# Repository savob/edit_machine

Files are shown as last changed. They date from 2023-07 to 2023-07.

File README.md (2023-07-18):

# Edit Machine

A hardware based goal tracker I made for a friend. The goal was simple: have buttons that illuminate LEDs to mark off completed tasks, another LED to flash when all goals are marked off, and to top it all off - a reset switch.

One requirement that was imposed on the project was that **we were to exclusively use material I already had laying about my apartment**, ideally reusing parts harvested off of other circuit boards I kept around for this purpose. 

Mechanically, there was a desire to have a space between the buttons and LEDs to record the goals corresponding to each row.

# Outcome

The final circuit was soldered on a perf(erated) board, which after *much* debugging made me long for a custom circuit board! It would probably surprize no one that this did not work on the first try. I'm relieved and a wee bit stupified that we didn't actually fry any chips in the process.

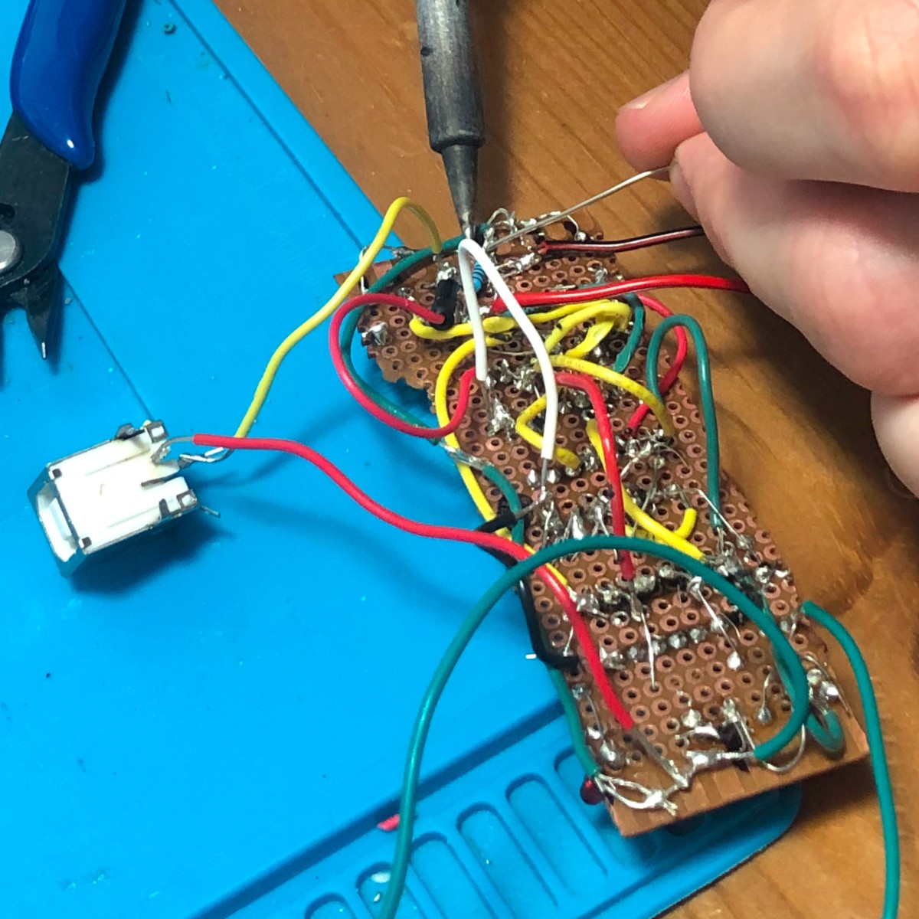
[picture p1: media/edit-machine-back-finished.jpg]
Rear view


By placing the chips in the middle I naturally created a space for the goals to be recorded inbetween the LEDs and the buttons. The chip cases can even act as fairly even supports for the writing pad above. *Note: that capacitor in the middle was bent down after the picture was taken.*

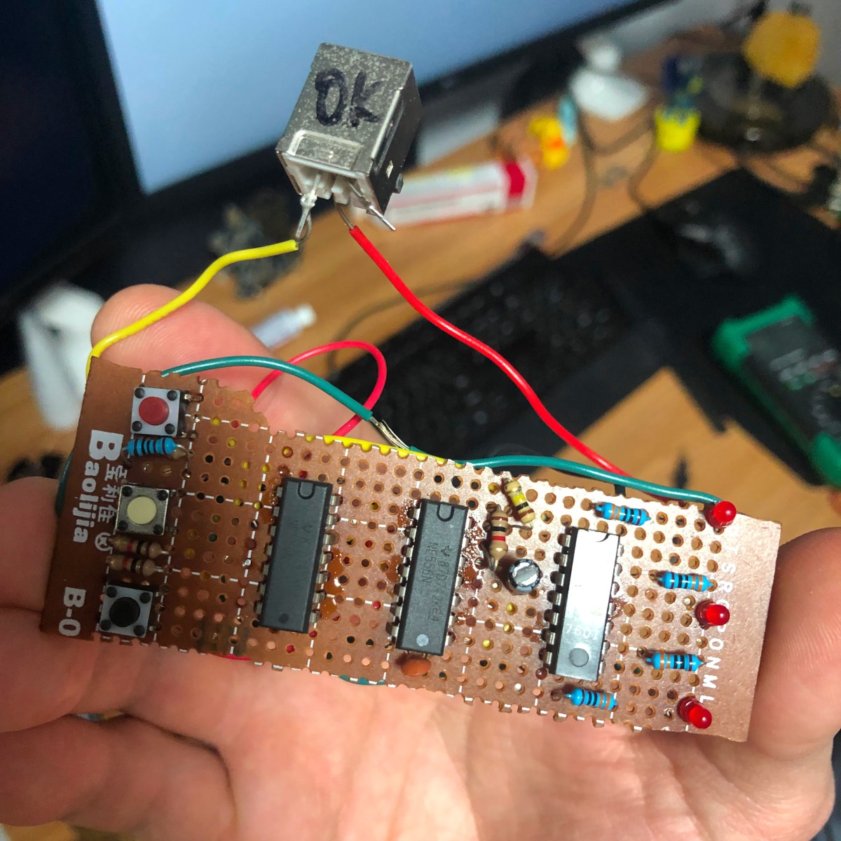
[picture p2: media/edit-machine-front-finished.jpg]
Front view


# The Circuitry

Originally I was planning to use some basic OR logic chips feeding into themselves to act as the toggles for the LEDs, however the chips I had were incorrectly labelled and were in fact XORs. So I ended up using some 556 timer chips as RS flip-flops for this instead. The driving for the final LED when all the goals are complete was accomplished using a chain of ANDs to combine the outputs for all the LEDs to enable the remaining timer in the 556's.

Schematic

I have made a preliminary custom circuit board which is a rough proxy of what the prototype was and is included as part of this project. Although it will function, it's dimesions and arrangement may change before I commit to having it made.

## Software Used

The circuit files were initially prepared in KiCad 7.0.5.

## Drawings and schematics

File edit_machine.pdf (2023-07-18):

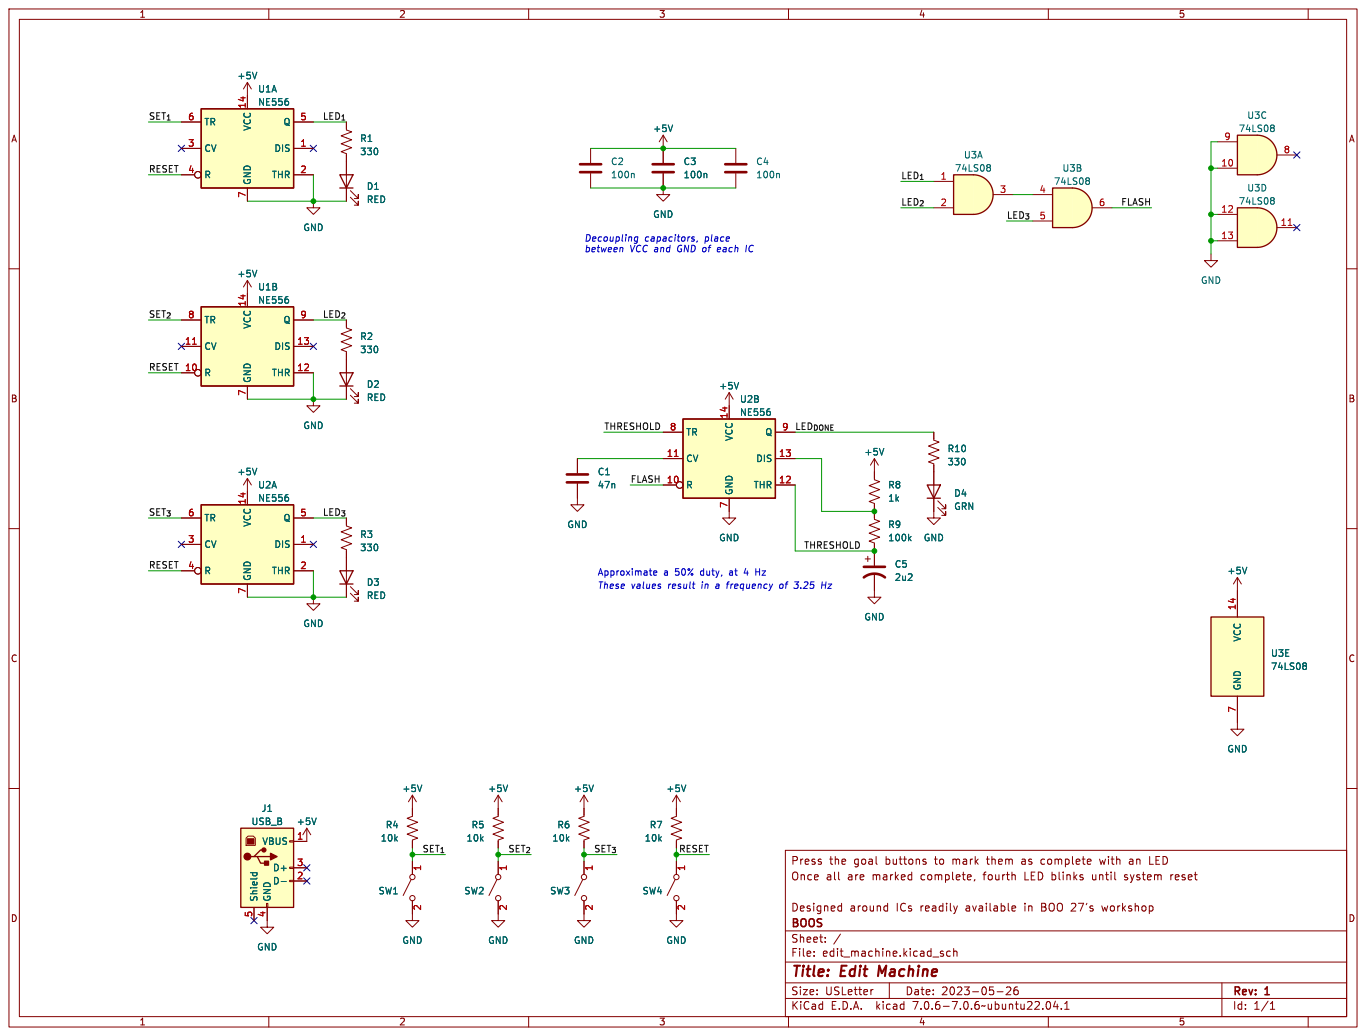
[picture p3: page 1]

between VCC and GND of each IC

Id: 1/1 Title: Edit Machine

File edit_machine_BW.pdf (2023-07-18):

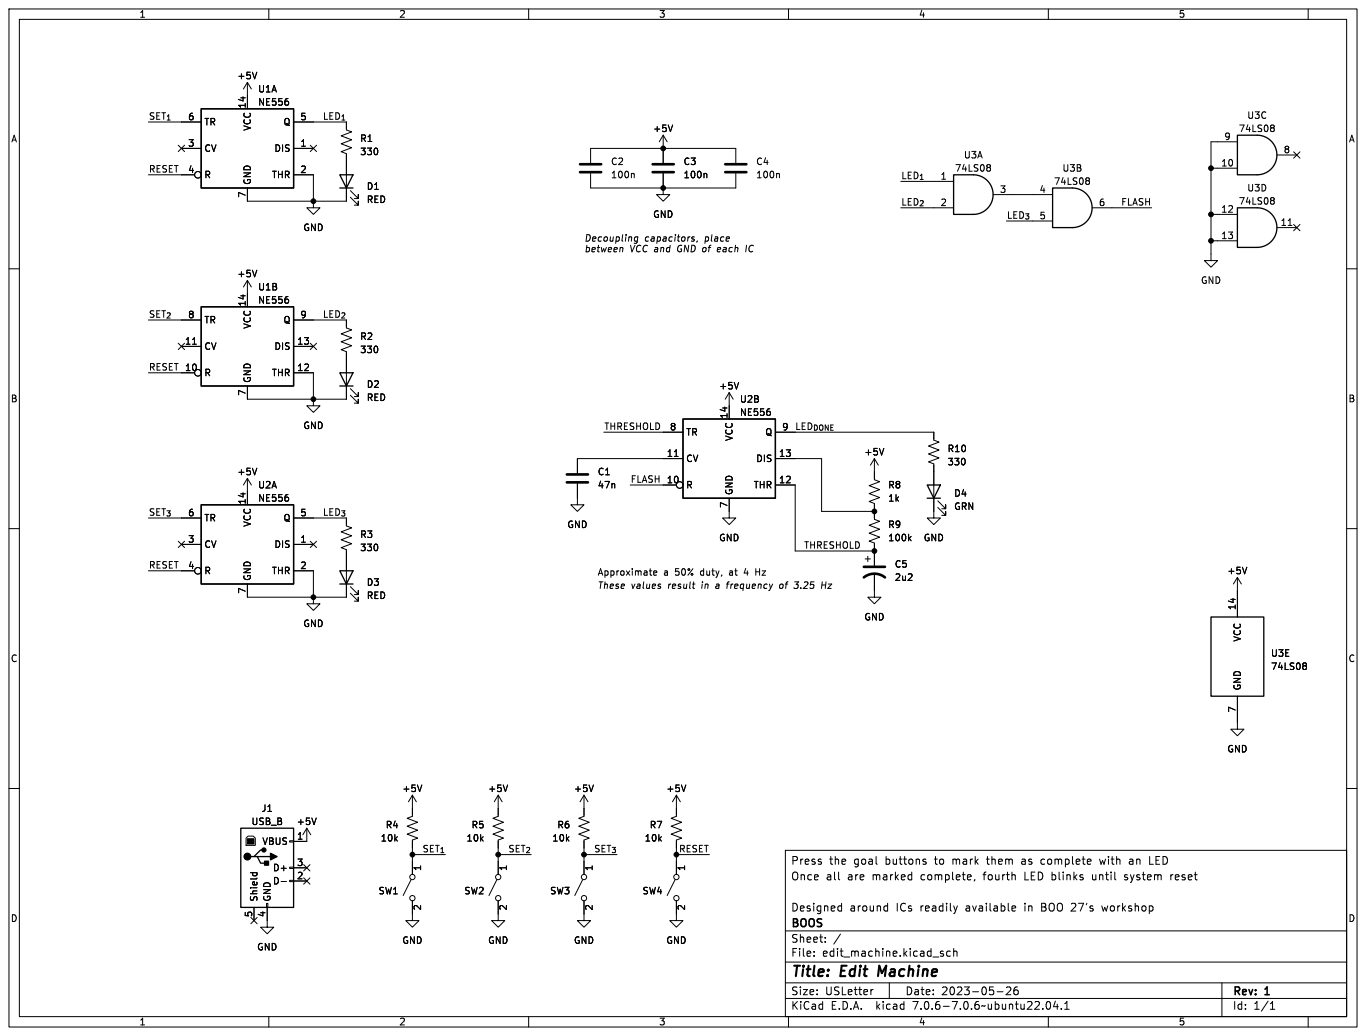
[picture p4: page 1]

between VCC and GND of each IC

Id: 1/1 Title: Edit Machine

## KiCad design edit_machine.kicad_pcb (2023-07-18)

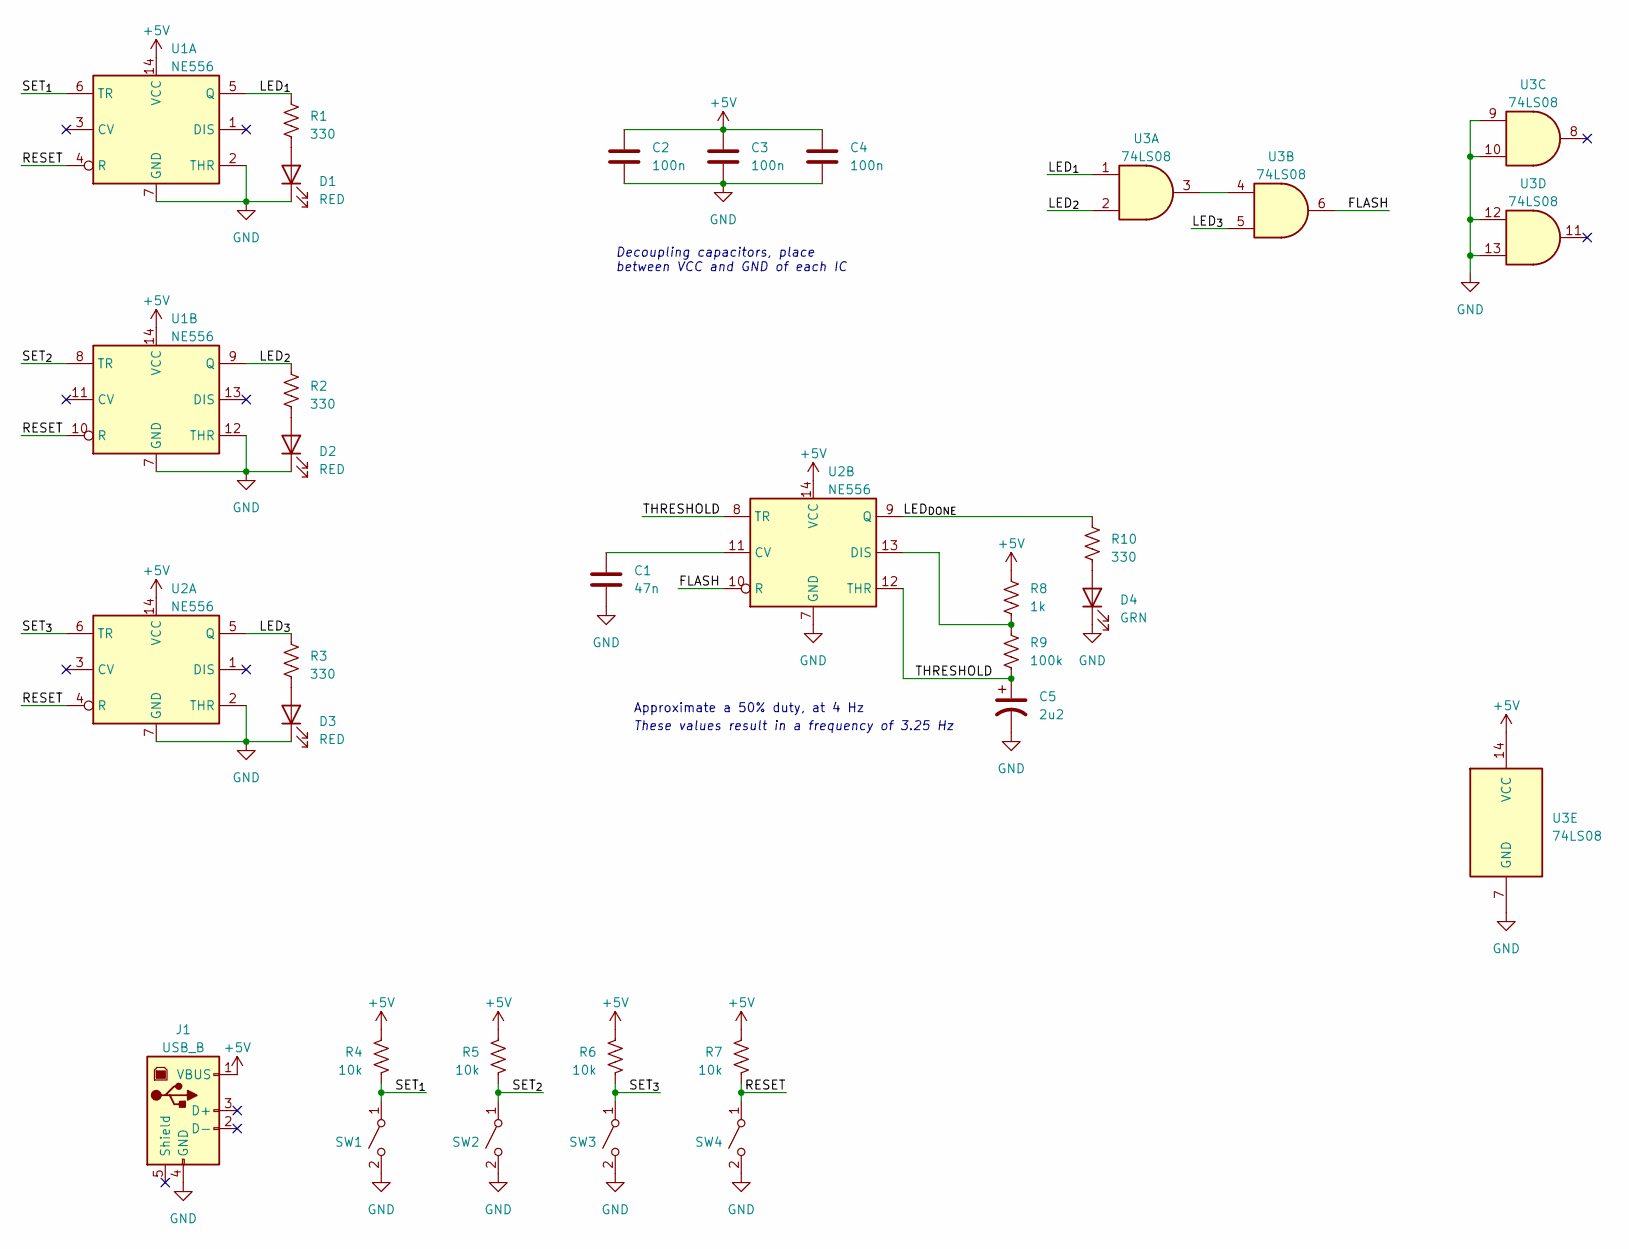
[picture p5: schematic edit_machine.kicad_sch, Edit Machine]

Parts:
C1: 47n; C_Disc_D3.4mm_W2.1mm_P2.50mm
C2, C3, C4: 100n; C_Disc_D3.8mm_W2.6mm_P2.50mm
C5: 2u2; CP_Radial_D4.0mm_P2.00mm
D1, D2, D3: RED; LED_D4.0mm
D4: GRN; LED_D4.0mm
J1: USB_B; USB_B_OST_USB-B1HSxx_Horizontal
R1, R2, R3, R10: 330; R_Axial_DIN0207_L6.3mm_D2.5mm_P7.62mm_Horizontal
R4, R5, R6, R7: 10k; R_Axial_DIN0207_L6.3mm_D2.5mm_P7.62mm_Horizontal
R8: 1k; R_Axial_DIN0207_L6.3mm_D2.5mm_P7.62mm_Horizontal
R9: 100k; R_Axial_DIN0207_L6.3mm_D2.5mm_P7.62mm_Horizontal
SW1, SW2, SW3, SW4: SW_SPST; SW_PUSH_6mm_H5mm
U1, U2: NE556; DIP-14_W7.62mm
U3: 74LS08; DIP-14_W7.62mm

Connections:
+5V: C2.1, C3.1, C4.1, J1.1 (VBUS), R4.1, R5.1, R6.1, R7.1, R8.1, U1.14 (VCC), U2.14 (VCC), U3.14 (VCC)
/FLASH: U2.10 (R), U3.6
/LED_{1}: R1.1, U1.5 (Q), U3.1
/LED_{2}: R2.1, U1.9 (Q), U3.2
/LED_{3}: R3.1, U2.5 (Q), U3.5
/LED_{DONE}: R10.1, U2.9 (Q)
/RESET: R7.2, SW4.1 (A), U1.4 (R), U1.10 (R), U2.4 (R)
/SET_{1}: R4.2, SW1.1 (A), U1.6 (TR)
/SET_{2}: R5.2, SW2.1 (A), U1.8 (TR)
/SET_{3}: R6.2, SW3.1 (A), U2.6 (TR)
/THRESHOLD: C5.1, R9.2, U2.8 (TR), U2.12 (THR)
GND: C1.2, C2.2, C3.2, C4.2, C5.2, D1.1 (K), D2.1 (K), D3.1 (K), D4.1 (K), J1.4 (GND), SW1.2 (B), SW2.2 (B), SW3.2 (B), SW4.2 (B), U1.2 (THR), U1.7 (GND), U1.12 (THR), U2.2 (THR), U2.7 (GND), U3.7 (GND), U3.9, U3.10, U3.12, U3.13
unnamed: D1.2 (A), R1.2
unnamed: D2.2 (A), R2.2
unnamed: D3.2 (A), R3.2
unnamed: D4.2 (A), R10.2
unnamed: C1.1, U2.11 (CV)
unnamed: R8.2, R9.1, U2.13 (DIS)
unnamed: U3.3, U3.4

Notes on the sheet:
Approximate a 50% duty, at 4 Hz
Decoupling capacitors, place between VCC and GND of each IC
These values result in a frequency of 3.25 Hz

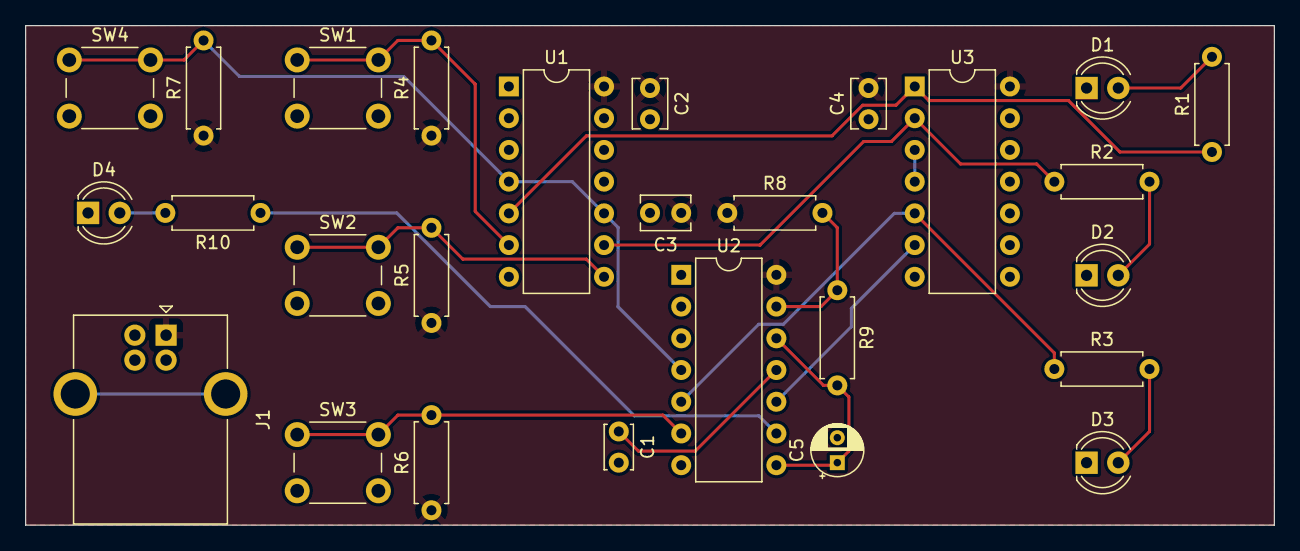
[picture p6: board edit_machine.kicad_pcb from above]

Board: 2 copper layers, 100.0 x 40.0 mm, 27 parts (0 on the bottom side), 19 nets.

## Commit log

2023-07-18 Upload of design files
    [edit_machine.kicad_pcb, edit_machine.kicad_sch]
2023-07-18 Updated SVG for schematic
